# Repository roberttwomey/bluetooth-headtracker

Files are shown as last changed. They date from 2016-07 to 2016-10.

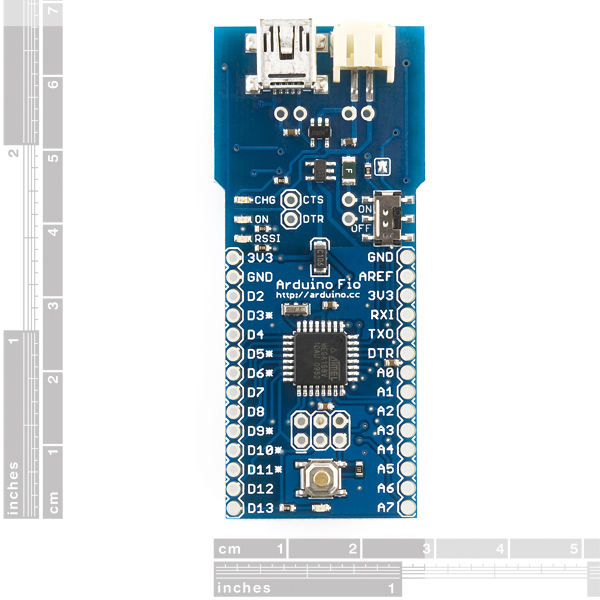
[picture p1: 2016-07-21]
reference/fio 10116-02.jpg

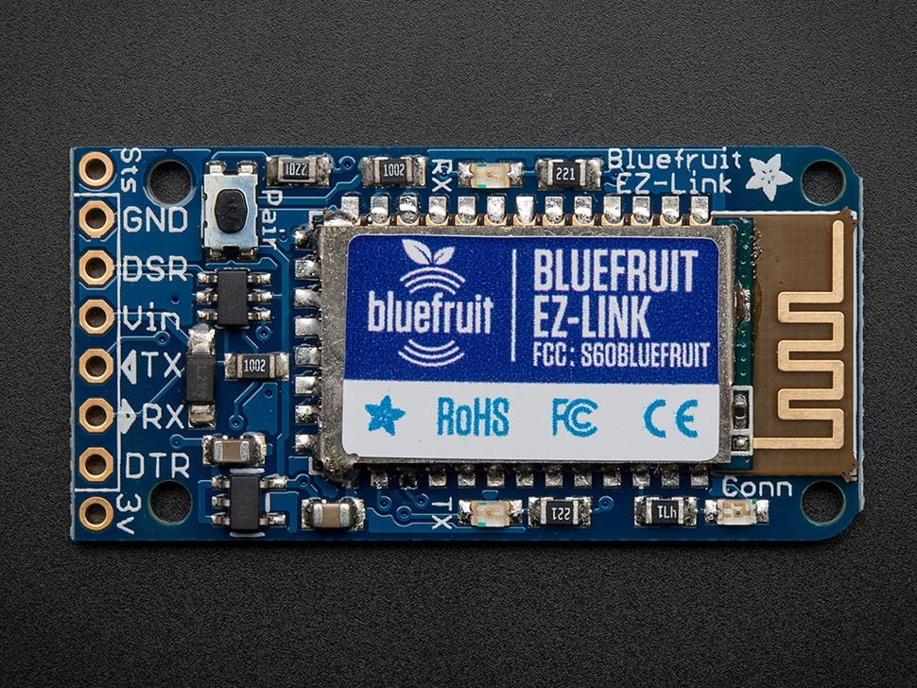
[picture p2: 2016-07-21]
reference/bluefruit ez-link serial 1588-00.jpg

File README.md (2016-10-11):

# bluetooth-headtracker

A simple bluetooth, rechargeable, 10DOF head-tracking device.

For use with the [Ambisonic ToolKit (ATK)](http://www.ambisonictoolkit.net/) , motion capture, and [Pan-Tilt](http://wiki.roberttwomey.com/Pan-Tilt) camera systems. 

A hardware, software, and 3d printed enclosure solution.

Developed for UW Center for Digital Arts and Experimental Media (DXARTS), July 2016

Robert Twomey - roberttwomey.com

# Usage

See the software options below. 

# Hardware

Built with simple, ready to order parts from common suppliers. Purchase 1 each of the following:
* Bluefruit EZ-Link - bluetooth modem w/ baud rate detection - http://www.adafruit.com/product/1588
* Arduino Pro Mini 3.3V - https://www.sparkfun.com/products/11114
* Power switch - https://www.sparkfun.com/products/102
* GY-86 - 10 DOF flight control module with MPU6050 + HMC5883L + MS5611 - http://www.amazon.com/Arrela-Control-Ms5611-Hmc5883l-Mpu6050/dp/B00KKJYMO6/
* LiPo Battery - https://www.sparkfun.com/products/731
* LiPo Charger - https://www.sparkfun.com/products/10217 (note you need to cut off the JST connector to fit it in the enclosure)
* Small quantity of stranded ribbon cable.

One of the following, needed to program the arduino. (One use only! Borrow from a friend?)
* FTDI Basic 3.3V - https://www.sparkfun.com/products/9873
* FTDI Cable 3.3V - http://www.adafruit.com/product/70

You can also choose to leave the LiPo charger out of the enclosure for small space savings.

# Arduino

[arduino/FreeIMU_quaternion/FreeIMU_quaternion.ino](arduino/FreeIMU_quaternion/FreeIMU_quaternion.ino)

We are using the straight FreeIMU_quaternion example from FreeIMU v0.4. This reads the attached sensors, calculates the AHRS quaternion, and transmits via serial print.

I've attached a copy of the FreeIMU_quaternion code here with the baud rate set to 38400, the max rate for the Arduino Pro Mini. 

# Processing

[processing/FreeIMU_cube](processing/FreeIMU_cube)

This is the demo app in Processing included with FreeIMU v0.4.

1. With the headtraker powered on, pair your computer with the bluefruit device.
2. Change the serial port screen to match your bluefruit device, for example ''/dev/tty.AdafruitEZ-Link3e2f-SPP'' on my system.
3. Run the example. Press 'h' to store the home position.

# Python
[python/head_through.py](python/head_through.py)

Simple python program to read from the IMU headtracker and record to file. Additionally opens second serial device and feeds values to pan-tilt camera in matching orientation. 

# Supercollider

[supercollider/ArduinoQuaternion/ArduinoQuaternion.sc](supercollider/ArduinoQuaternion/ArduinoQuaternion.sc)

A class based on the Arduino quark that connects to the paired bluetooth device as a serial port, and parses the binary data.

[supercollider/bt_headtrack_test.scd](supercollider/bt_headtrack_test.scd)

A sandbox program to try out the headtrack class.

# Solidworks

[solidworks/realv4/](solidworks/realv4/)

Solid model of enclosures and circuitry.

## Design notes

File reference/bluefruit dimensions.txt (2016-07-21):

Dimensions: 20.4mm / 0.8" x 41mm / 1.6" x 4mm / 0.2"

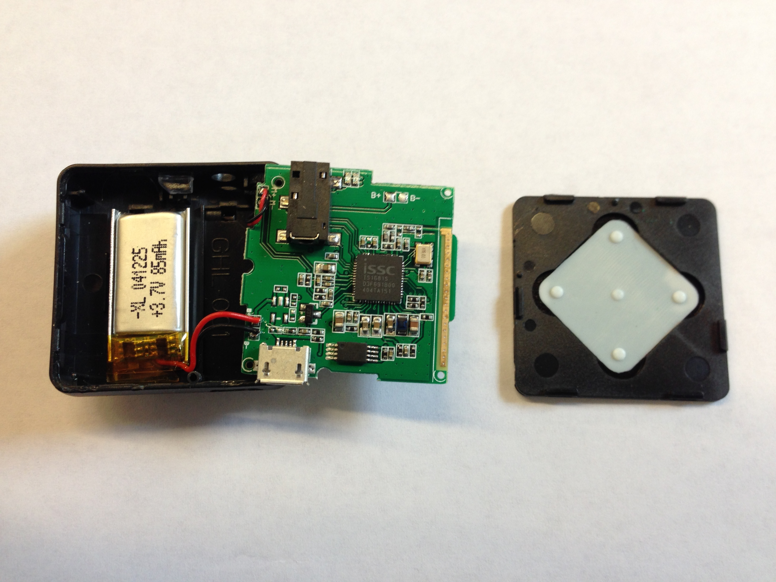
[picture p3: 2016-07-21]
reference/bt-audio/bt audio receiver.jpg

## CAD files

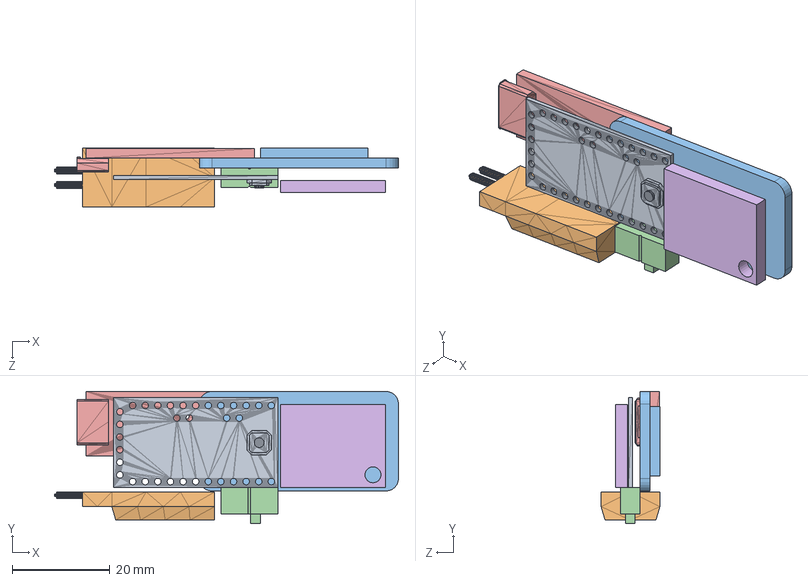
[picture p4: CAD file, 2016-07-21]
solidworks/compact/bluetooth_headtracker.SLDASM
70.2 x 27.0 x 12.0 mm
Arduino Pro Mini 328 - DEV-11113
Polymer Lithium Ion Battery - 110mAh PRT-00731
bluefruit-ezlink
SPDT Mini Power Switch COM-0010
LiPo Charger Basic - Micro-USB PRT-10217 no jst
GY-86

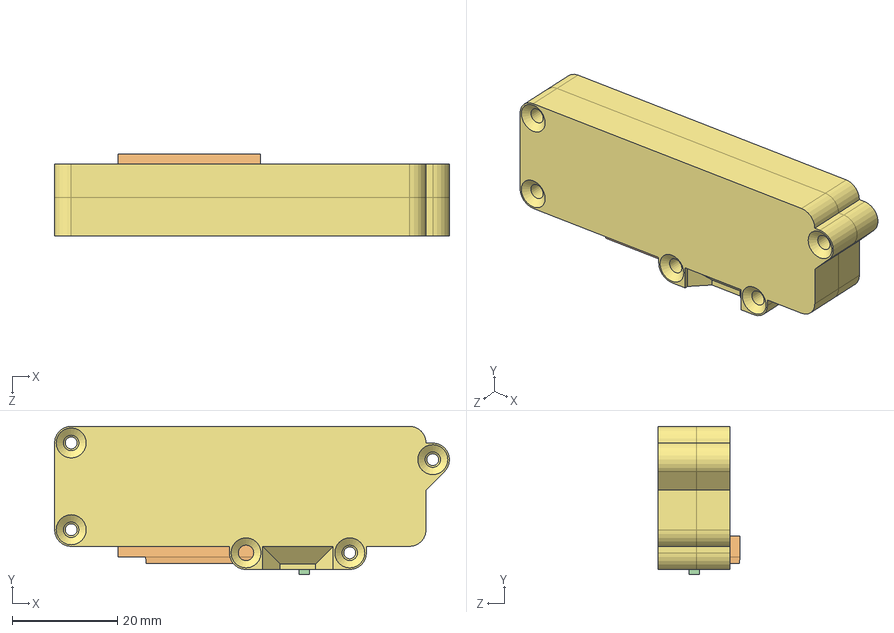
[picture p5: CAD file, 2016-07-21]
solidworks/v4/bluetooth_headtracker.SLDASM
75.1 x 28.2 x 15.6 mm
Arduino Pro Mini 328 - DEV-11113
lipo_small
bluefruit-ezlink
SPDT Mini Power Switch COM-0010
LiPo Charger Micro-USB PRT-10217 - no jst
GY-86
enclosure3

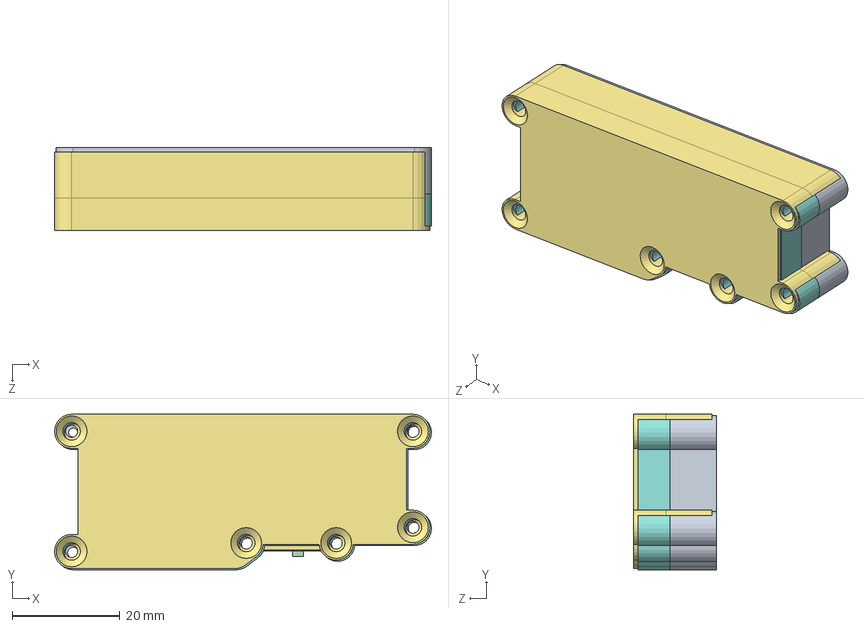
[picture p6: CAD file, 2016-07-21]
solidworks/realv4/bluetooth_headtracker.SLDASM
69.9 x 28.8 x 15.3 mm
lipo_small
SPDT Mini Power Switch COM-0010
LiPo Charger Micro-USB PRT-10217 - no jst
GY-86
enc_bot
enc_top

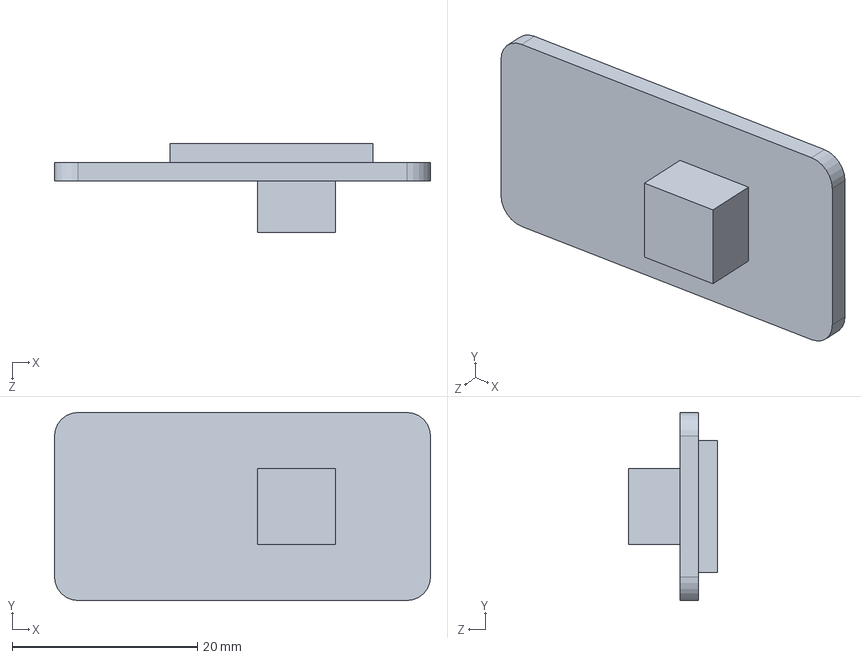
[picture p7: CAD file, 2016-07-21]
solidworks/realv4/bluefruit-ezlink.SLDPRT
40.6 x 20.3 x 9.65 mm

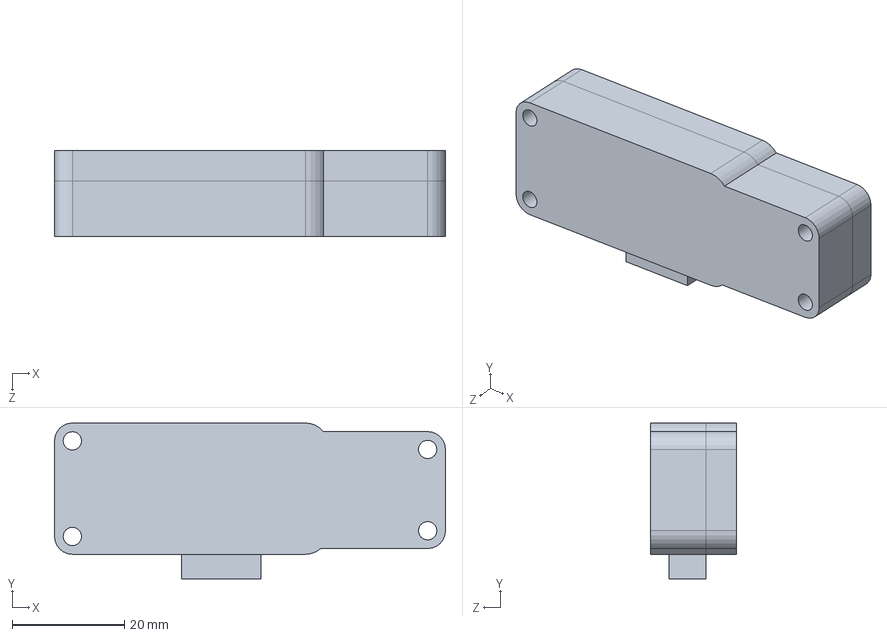
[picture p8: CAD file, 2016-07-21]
solidworks/v4/enclosure.SLDPRT
69.6 x 27.8 x 15.2 mm

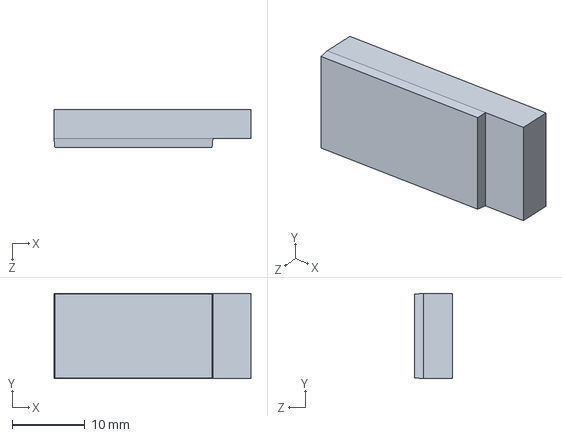
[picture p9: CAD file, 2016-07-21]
solidworks/compact/lipo_small.SLDPRT
27.1 x 11.8 x 5.25 mm

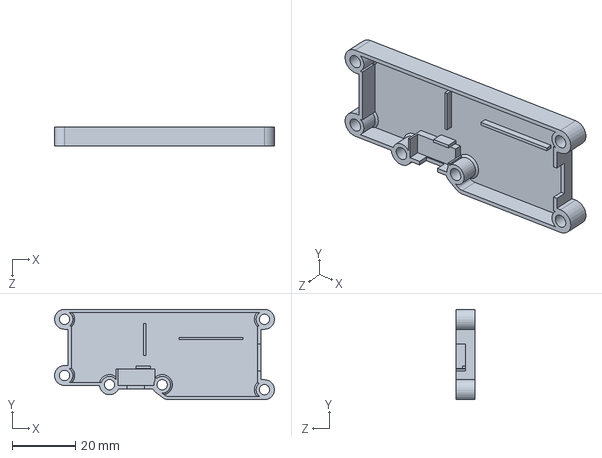
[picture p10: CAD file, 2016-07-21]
solidworks/realv4/enc_bot.sldprt
69.6 x 28.6 x 5.99 mm

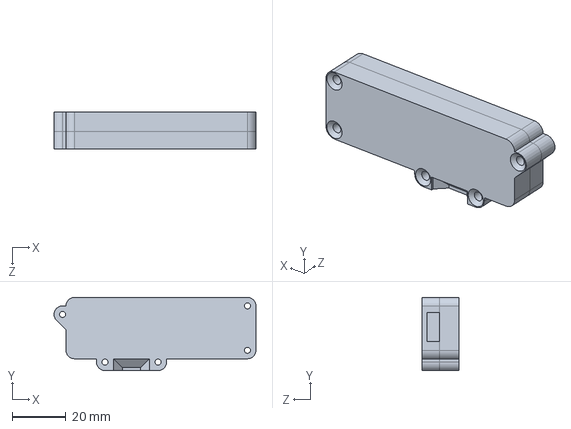
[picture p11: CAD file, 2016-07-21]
solidworks/v4/enclosure3.SLDPRT
75.1 x 27.3 x 13.7 mm

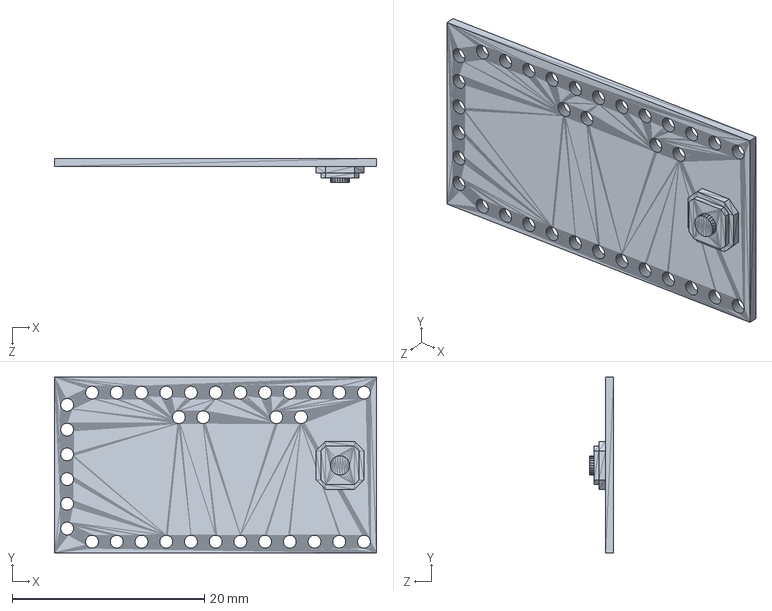
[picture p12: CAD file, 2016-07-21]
solidworks/realv4/Arduino Pro Mini 328 - DEV-11113.SLDPRT
33.5 x 18.3 x 2.55 mm

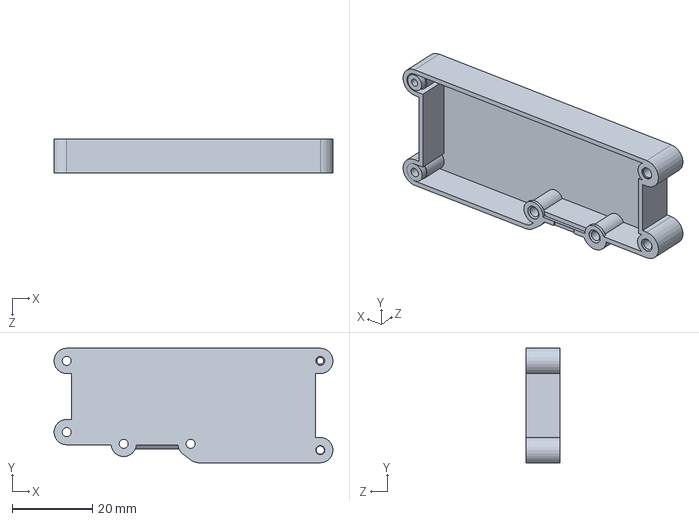
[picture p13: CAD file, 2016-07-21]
solidworks/realv4/enc_top.sldprt
69.6 x 28.6 x 8.56 mm

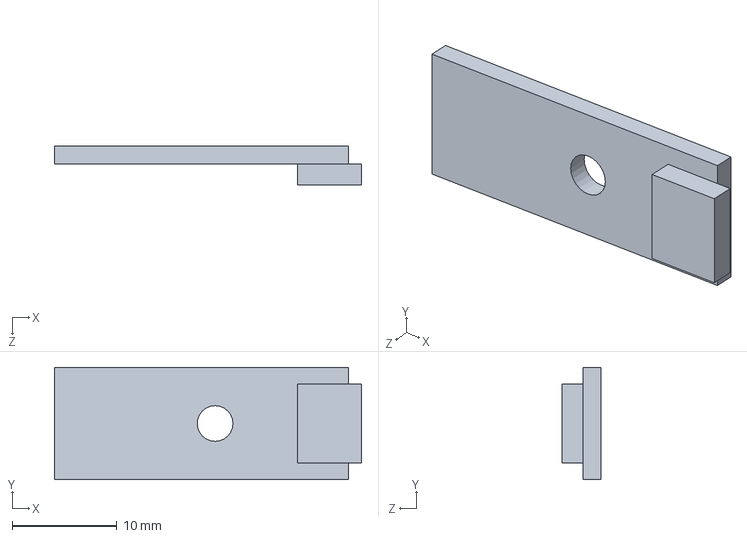
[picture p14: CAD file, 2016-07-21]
solidworks/v4/LiPo Charger Micro-USB PRT-10217 - no jst.SLDPRT
29.2 x 10.7 x 3.70 mm

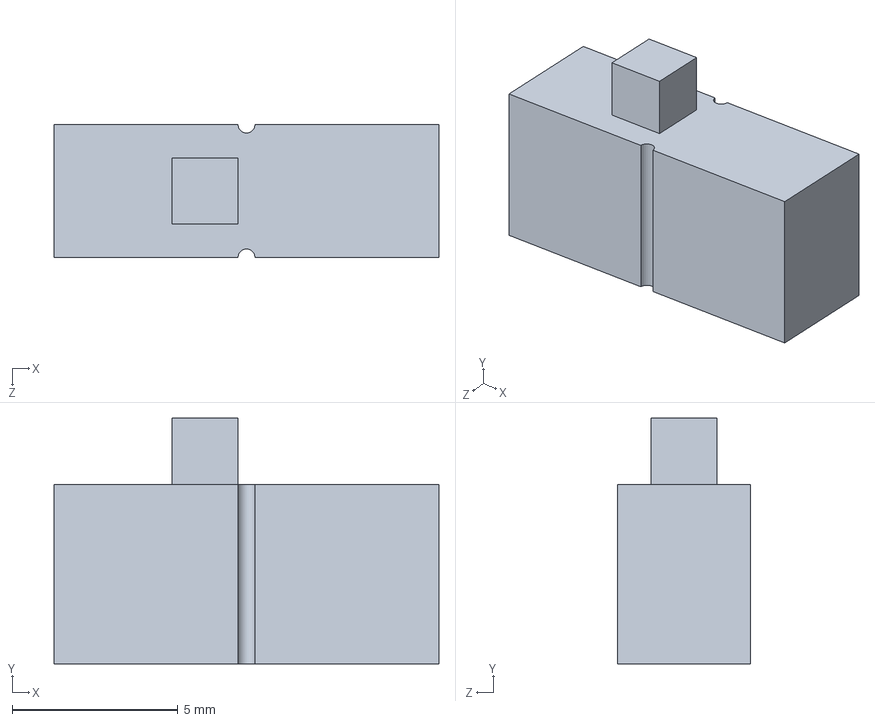
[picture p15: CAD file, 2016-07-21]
solidworks/compact/SPDT Mini Power Switch COM-0010.SLDPRT
11.6 x 7.41 x 4.00 mm

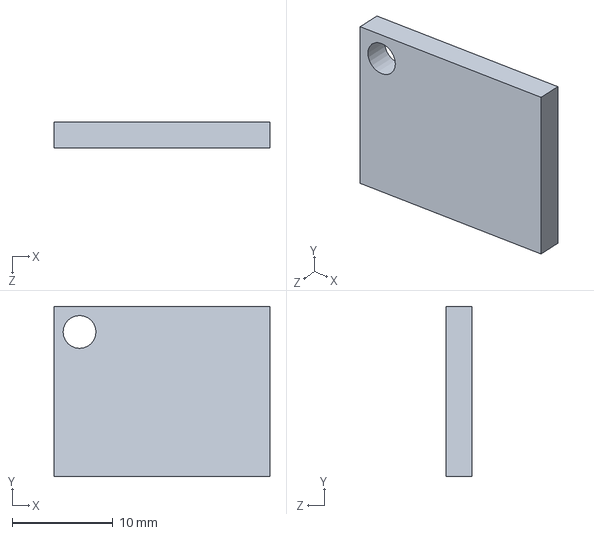
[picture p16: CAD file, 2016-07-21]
solidworks/realv4/GY-86.SLDPRT
21.5 x 16.9 x 2.54 mm

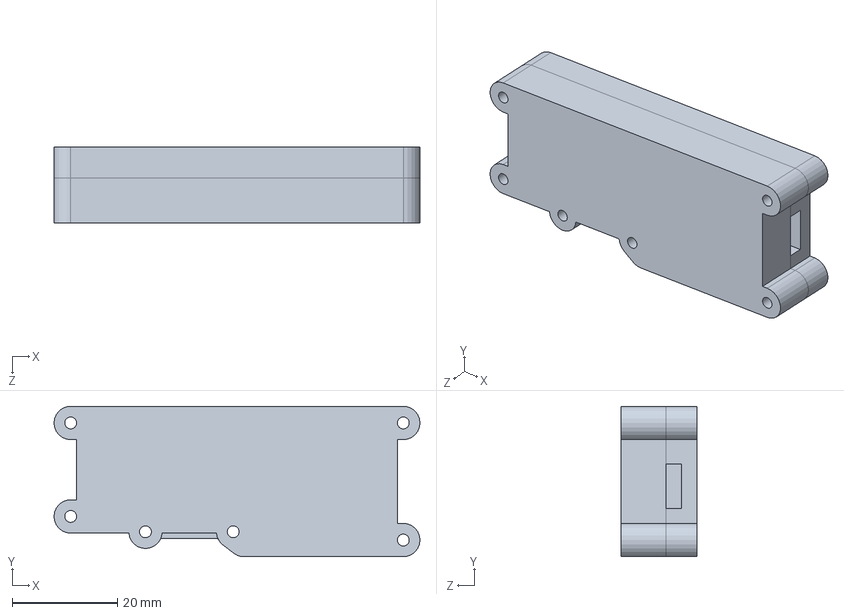
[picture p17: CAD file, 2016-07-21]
solidworks/realv4/enclosure3.SLDPRT
69.6 x 28.6 x 14.5 mm

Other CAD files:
solidworks/compact/enclosure3.SLDPRT
solidworks/realv4/3dprinting/enc_bot.STL
solidworks/realv4/3dprinting/enc_top.STL
solidworks/v2/arduino fio.SLDPRT
solidworks/v2/enclosure.SLDPRT
solidworks/v2/headtrack enclosure.SLDASM
solidworks/v2/ht_bot.STL
solidworks/v2/ht_bot.sldprt
solidworks/v2/ht_top.STL
solidworks/v2/ht_top.sldprt
solidworks/v3 old/LiPo Charger Basic - Micro-USB PRT-10217 no jst.SLDPRT
solidworks/v3 old/Polymer Lithium Ion Battery - 110mAh PRT-00731.SLDPRT
solidworks/v3 old/enclosure3.SLDPRT
solidworks/v4/Part7.sldprt

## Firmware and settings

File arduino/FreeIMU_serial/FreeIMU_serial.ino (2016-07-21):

/**
 * FreeIMU library serial communication protocol
*/

#include <ADXL345.h>
#include <bma180.h>
#include <HMC58X3.h>
#include <ITG3200.h>
#include <MS561101BA.h>
#include <I2Cdev.h>
#include <MPU60X0.h>
#include <EEPROM.h>

//#define DEBUG
#include "DebugUtils.h"
#include "CommunicationUtils.h"
#include "FreeIMU.h"
#include <Wire.h>
#include <SPI.h>


float q[4];
int raw_values[9];
float ypr[3]; // yaw pitch roll
char str[256];
float val[9];


// Set the FreeIMU object
FreeIMU my3IMU = FreeIMU();
//The command from the PC
char cmd;

void setup() {
  Serial.begin(38400);
  Wire.begin();
  my3IMU.init(true);
  
  // LED
  pinMode(13, OUTPUT);
}


void loop() {
  if(Serial.available()) {
    cmd = Serial.read();
    if(cmd=='v') {
      sprintf(str, "FreeIMU library by %s, FREQ:%s, LIB_VERSION: %s, IMU: %s", FREEIMU_DEVELOPER, FREEIMU_FREQ, FREEIMU_LIB_VERSION, FREEIMU_ID);
      Serial.print(str);
      Serial.print('\n');
    }
    else if(cmd=='r') {
      uint8_t count = serial_busy_wait();
      for(uint8_t i=0; i<count; i++) {
        my3IMU.getRawValues(raw_values);
        sprintf(str, "%d,%d,%d,%d,%d,%d,%d,%d,%d,%d,%d,", raw_values[0], raw_values[1], raw_values[2], raw_values[3], raw_values[4], raw_values[5], raw_values[6], raw_values[7], raw_values[8], raw_values[9], raw_values[10]);
        Serial.print(str);
        Serial.print('\n');
      }
    }
    else if(cmd=='b') {
      uint8_t count = serial_busy_wait();
      for(uint8_t i=0; i<count; i++) {
        #if HAS_ITG3200()
          my3IMU.acc.readAccel(&raw_values[0], &raw_values[1], &raw_values[2]);
          my3IMU.gyro.readGyroRaw(&raw_values[3], &raw_values[4], &raw_values[5]);
        #else // MPU6050
          my3IMU.accgyro.getMotion6(&raw_values[0], &raw_values[1], &raw_values[2], &raw_values[3], &raw_values[4], &raw_values[5]);
        #endif
        writeArr(raw_values, 6, sizeof(int)); // writes accelerometer and gyro values
        #if IS_9DOM()
          my3IMU.magn.getValues(&raw_values[0], &raw_values[1], &raw_values[2]);
          writeArr(raw_values, 3, sizeof(int));
        #endif
        Serial.println();
      }
    }
    else if(cmd == 'q') {
      uint8_t count = serial_busy_wait();
      for(uint8_t i=0; i<count; i++) {
        my3IMU.getQ(q);
        serialPrintFloatArr(q, 4);
        Serial.println("");
      }
    }
    #ifndef CALIBRATION_H
    else if(cmd == 'c') {
      const uint8_t eepromsize = sizeof(float) * 6 + sizeof(int) * 6;
      while(Serial.available() < eepromsize) ; // wait until all calibration data are received
      EEPROM.write(FREEIMU_EEPROM_BASE, FREEIMU_EEPROM_SIGNATURE);
      for(uint8_t i = 1; i<(eepromsize + 1); i++) {
        EEPROM.write(FREEIMU_EEPROM_BASE + i, (char) Serial.read());
      }
      my3IMU.calLoad(); // reload calibration
      // toggle LED after calibration store.
      digitalWrite(13, HIGH);
      delay(1000);
      digitalWrite(13, LOW);
    }
    #endif
    else if(cmd == 'C') { // check calibration values
      Serial.print("acc offset: ");
      Serial.print(my3IMU.acc_off_x);
      Serial.print(",");
      Serial.print(my3IMU.acc_off_y);
      Serial.print(",");
      Serial.print(my3IMU.acc_off_z);
      Serial.print("\n");
      
      Serial.print("magn offset: ");
      Serial.print(my3IMU.magn_off_x);
      Serial.print(",");
      Serial.print(my3IMU.magn_off_y);
      Serial.print(",");
      Serial.print(my3IMU.magn_off_z);
      Serial.print("\n");
      
      Serial.print("acc scale: ");
      Serial.print(my3IMU.acc_scale_x);
      Serial.print(",");
      Serial.print(my3IMU.acc_scale_y);
      Serial.print(",");
      Serial.print(my3IMU.acc_scale_z);
      Serial.print("\n");
      
      Serial.print("magn scale: ");
      Serial.print(my3IMU.magn_scale_x);
      Serial.print(",");
      Serial.print(my3IMU.magn_scale_y);
      Serial.print(",");
      Serial.print(my3IMU.magn_scale_z);
      Serial.print("\n");
    }
    else if(cmd == 'd') { // debugging outputs
      while(1) {
        my3IMU.getRawValues(raw_values);
        sprintf(str, "%d,%d,%d,%d,%d,%d,%d,%d,%d,%d,%d,", raw_values[0], raw_values[1], raw_values[2], raw_values[3], raw_values[4], raw_values[5], raw_values[6], raw_values[7], raw_values[8], raw_values[9], raw_values[10]);
        Serial.print(str);
        Serial.print('\n');
        my3IMU.getQ(q);
        serialPrintFloatArr(q, 4);
        Serial.println("");
        my3IMU.getYawPitchRoll(ypr);
        Serial.print("Yaw: ");
        Serial.print(ypr[0]);
        Serial.print(" Pitch: ");
        Serial.print(ypr[1]);
        Serial.print(" Roll: ");
        Serial.print(ypr[2]);
        Serial.println("");
      }
    }
  }
}

char serial_busy_wait() {
  while(!Serial.available()) {
    ; // do nothing until ready
  }
  return Serial.read();
}

const int EEPROM_MIN_ADDR = 0;
const int EEPROM_MAX_ADDR = 511;

void eeprom_serial_dump_column() {
  // counter
  int i;

  // byte read from eeprom
  byte b;

  // buffer used by sprintf
  char buf[10];

  for (i = EEPROM_MIN_ADDR; i <= EEPROM_MAX_ADDR; i++) {
    b = EEPROM.read(i);
    sprintf(buf, "%03X: %02X", i, b);
    Serial.println(buf);
  }
}

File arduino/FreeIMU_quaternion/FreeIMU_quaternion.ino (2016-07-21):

//
// FreeIMU Quaternion example to run with bluetooth headtracker. 
//
// taken from FreeIMU library - 
//
// headtracker - http://wiki.roberttwomey.com/Bluetooth_Headtracker
// 
//   rtwomey@uw.edu
//

#include <ADXL345.h>
#include <bma180.h>
#include <HMC58X3.h>
#include <ITG3200.h>
#include <MS561101BA.h>
#include <I2Cdev.h>
#include <MPU60X0.h>
#include <EEPROM.h>

//#define DEBUG
#include "DebugUtils.h"
#include "CommunicationUtils.h"
#include "FreeIMU.h"
#include <Wire.h>
#include <SPI.h>


float q[4];

// Set the FreeIMU object
FreeIMU my3IMU = FreeIMU();

void setup() {
  Serial.begin(38400); // max rate for Arduino Pro Mini 3.3V
  Wire.begin();
  
  delay(5);
  my3IMU.init();
  delay(5);
}


void loop() { 
  my3IMU.getQ(q);
  serialPrintFloatArr(q, 4);
  //Serial.print("x");
  Serial.println("");
  delay(20);
}
